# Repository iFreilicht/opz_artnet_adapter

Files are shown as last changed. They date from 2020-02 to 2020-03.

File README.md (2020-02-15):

# OP-Z Artnet Adapter

This is the software for an OP-Z to Artnet adapter.
It can be connected via the USB-C connector on the OP-Z to control
Artnet-powered lighting fixtures and other devices via WiFi.

## Hardware

The module consists of an FTDI232 chip - immitating an ENTTEC DMX USB Pro -
and an ESP-01 module. Some passive components are required.

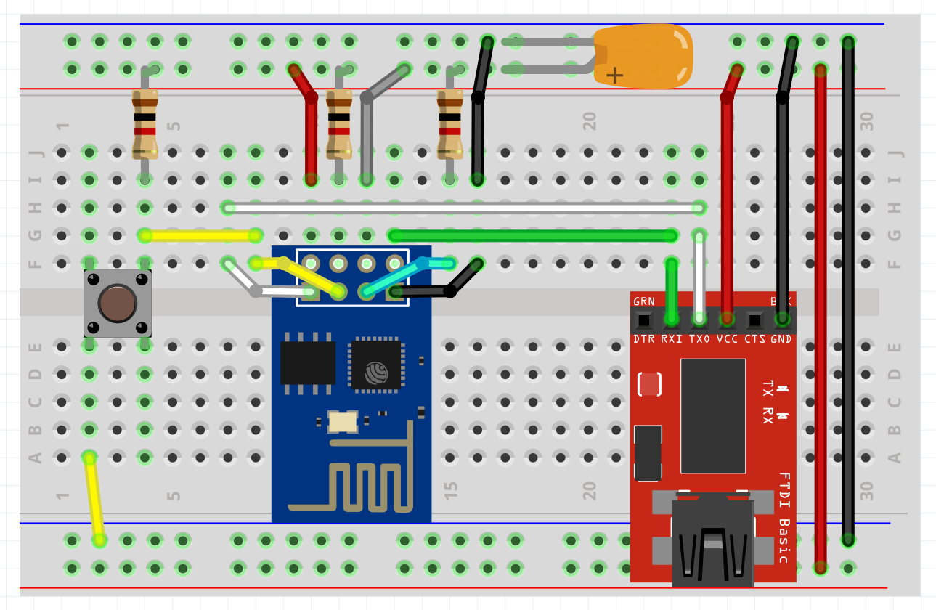
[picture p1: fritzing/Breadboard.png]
Breadboard view


For more info about building the adapter, check out [fritzing/README.md](fritzing/README.md).

## Settings

Settings for your local Artnet setup can be changed in `artnet_settings.h`.
For changing the dmx configuration, check out [dmx/README.md](dmx/README.md).

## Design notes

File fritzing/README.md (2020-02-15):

# Fritzing Design Files

This folder contains the fritzing sketch and parts which help rebuild the
adapter on a breadboard.

You may have to import `ESP8266-01.fzpz` into your parts library, it is
not part of any default library.

Breaboard
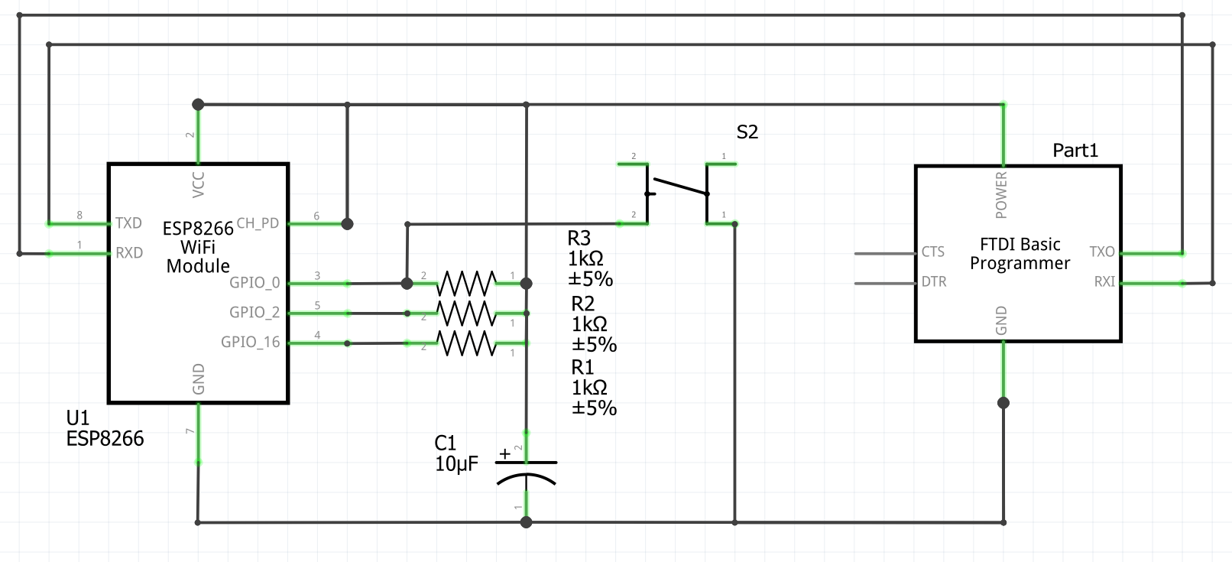
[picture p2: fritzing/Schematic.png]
Schematic


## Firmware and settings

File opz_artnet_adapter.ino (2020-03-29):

/*
 *  Adapter of OP-Z to Artnet via WiFi.
 *
 *  This has to be run on an ESP8266 (I recommend the ESP-01 module)
 *  with an FTDI232 as the USB-to-serial converter.
 */

#include <ArtnetWifi.h>
#include <DMXUSB.h>
#include <ESP8266WiFi.h>

// Modify the settings headers to fit your setup
#include "artnet_settings.h"
#include "dmx/16_led_strip/settings.h"

ArtnetWifi artnet;

// Callback on incoming DMX packet
void dmxCallback(int universe, char buffer[512]) {
  // Get value for each channel
  for (int i = 0; i < num_channels; i++) {
    int channel = i;
    int value = buffer[i];
    artnet.setByte(channel, value);
  }
  // send out the Art-Net DMX data
  artnet.write();
}

// Initialise DMX
DMXUSB dmxUsb(Serial, baud_rate, 0, dmxCallback);

void setup() {
  Serial.begin(baud_rate);
  delay(10);

  // Connect to WiFi network
  WiFi.hostname("OP-Z Artnet");
  WiFi.mode(WIFI_STA);
  WiFi.begin(ssid, password);

  while (WiFi.status() != WL_CONNECTED) {
    delay(500);
  }

  // Connect to Artnet host
  artnet.begin(host);
  artnet.setLength(num_channels);
  artnet.setUniverse(universe);
}

void loop() {
  dmxUsb.listen();
  // Sleep to reduce power consumption
  // This is necessary, otherwise the OP-Z will refuse to provide power
  delay(40);
}

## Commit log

2019-03-16 Send Artnet data to other device
2019-10-17 Pass DMX through
    A draft. Compiles, but doesn't work with OP-Z
    because the only FTDI currently supported is the FT232.
2019-10-17 Use I2C for transfer
    Doesn't work yet because onReceive is not implemented for ESP32.
2020-02-12 Make code run on ESP8266
    This works, but is not very reliable. The ESP crashes often.
    We need to conserve power more cleverly.
2020-02-12 Simplify sleep
    Just delaying is more reliable than actively specifying the sleep state.
    The power troubles were eliminated with a smoothing capacitor accross
    the 3.3V output of the FT232.
2020-02-15 Add fritzing files
    [opz_artnet_adapter.fzz]
2020-02-15 Fix case of file type
